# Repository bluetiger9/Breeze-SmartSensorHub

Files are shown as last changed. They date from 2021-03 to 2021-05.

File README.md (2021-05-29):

# Breeze: Smart Environmental Sensor Hub



Battery & Solar powered Sensor Hub with ML capabilities and supports a wide variety of Sensors and Communication Modules.

**Hackster.io**:
https://www.hackster.io/bluetiger9/breeze-smart-environmental-sensor-hub-fa496e

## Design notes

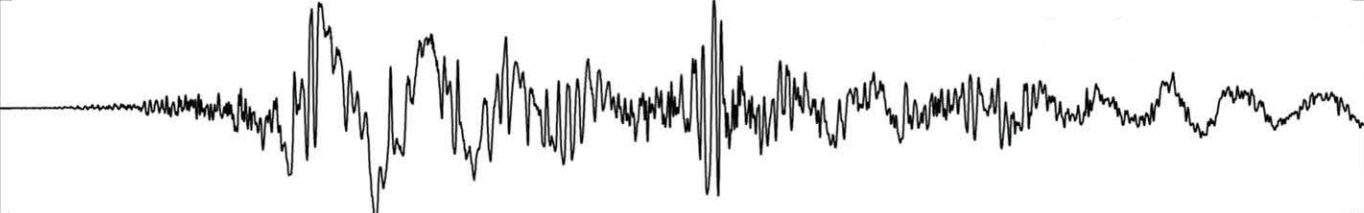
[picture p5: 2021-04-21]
Models/earthquake_data/s5-01-Y-scale-150cms2-70sec.png

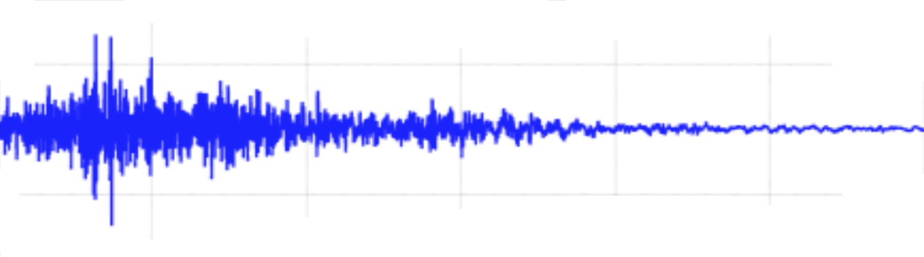
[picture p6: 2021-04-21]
Models/earthquake_data/s1-01-Z-scale-1G-60sec.png

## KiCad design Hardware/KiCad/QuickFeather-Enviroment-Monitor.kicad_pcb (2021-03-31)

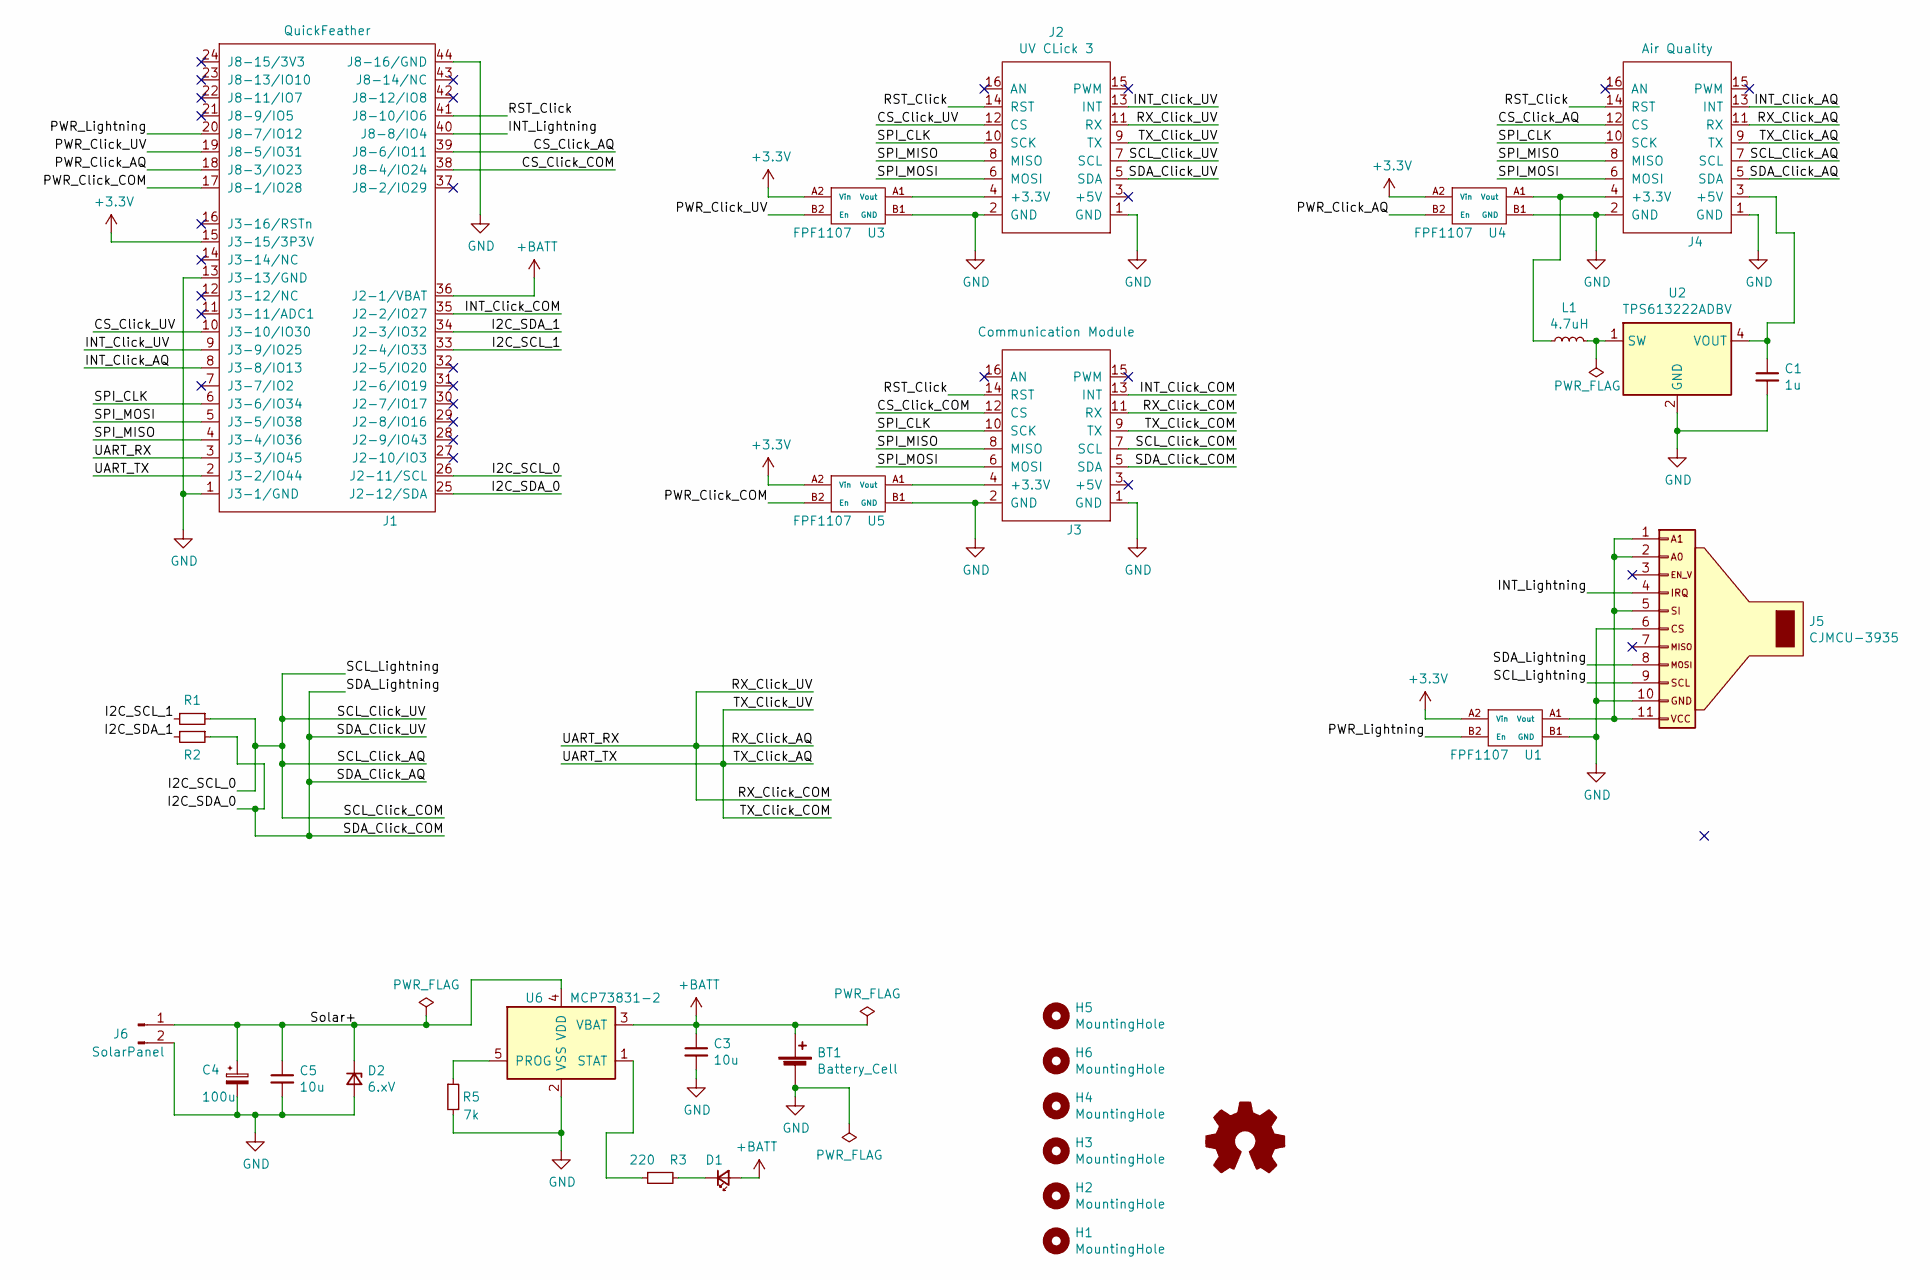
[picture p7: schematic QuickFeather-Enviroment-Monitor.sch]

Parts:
BT1: Battery_Cell; BatteryHolder_Keystone_1042_1x18650
C1: 1u; C_0805_2012Metric
C3, C5: 10u; C_0805_2012Metric
C4: 100u; CP_Radial_D6.3mm_P2.50mm
D1: LED_Small; LED_0805_2012Metric
D2: 6.xV; D_SMA
H1, H2, H3, H4, H5, H6: MountingHole
J1: QuickFeather; quickfeather
J2: UV CLick 3; MikroBUS-Small
J3: Communication Module; MikroBUS-Medium
J4: Air Quality; MikroBUS-Small
J5: CJMCU-3935
J6: SolarPanel; PinHeader_1x02_P2.54mm_Vertical
L1: 4.7uH; L_0805_2012Metric
R1, R2: nc; R_0402_1005Metric_Pad0.72x0.64mm_HandSolder
R3: 220; R_0805_2012Metric
R5: 7k; R_0805_2012Metric
U1, U3, U4, U5: FPF1107; BGA4C40P2X2_84X84X60N
U2: TPS613222ADBV; SOT-23-5
U6: MCP73831-2; SOT-23-5

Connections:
+3V3: J1.15 (J3-15/3P3V), U1.A2 (Vin), U3.A2 (Vin), U4.A2 (Vin), U5.A2 (Vin)
+BATT: BT1.1 (+), C3.1, D1.2 (A), J1.36 (J2-1/VBAT), U6.3 (VBAT)
/CS_Click_AQ: J1.39 (J8-6/IO11), J4.12 (CS)
/CS_Click_COM: J1.38 (J8-4/IO24), J3.12 (CS)
/CS_Click_UV: J1.10 (J3-10/IO30), J2.12 (CS)
/I2C_SCL_0: J1.26 (J2-11/SCL), J2.7 (SCL), J3.7 (SCL), J4.7 (SCL), J5.9, R1.1
/I2C_SCL_1: J1.33 (J2-4/IO33), R1.2
/I2C_SDA_0: J1.25 (J2-12/SDA), J2.5 (SDA), J3.5 (SDA), J4.5 (SDA), J5.8, R2.1
/I2C_SDA_1: J1.34 (J2-3/IO32), R2.2
/INT_Click_AQ: J1.8 (J3-8/IO13), J4.13 (INT)
/INT_Click_COM: J1.35 (J2-2/IO27), J3.13 (INT)
/INT_Click_UV: J1.9 (J3-9/IO25), J2.13 (INT)
/INT_Lightning: J1.40 (J8-8/IO4), J5.4
/PWR_Click_AQ: J1.18 (J8-3/IO23), U4.B2 (En)
/PWR_Click_COM: J1.17 (J8-1/IO28), U5.B2 (En)
/PWR_Click_UV: J1.19 (J8-5/IO31), U3.B2 (En)
/PWR_Lightning: J1.20 (J8-7/IO12), U1.B2 (En)
/RST_Click: J1.41 (J8-10/IO6), J2.14 (RST), J3.14 (RST), J4.14 (RST)
/RX_Click_AQ: J1.3 (J3-3/IO45), J2.11 (RX), J3.11 (RX), J4.11 (RX)
/SPI_CLK: J1.6 (J3-6/IO34), J2.10 (SCK), J3.10 (SCK), J4.10 (SCK)
/SPI_MISO: J1.4 (J3-4/IO36), J2.8 (MISO), J3.8 (MISO), J4.8 (MISO)
/SPI_MOSI: J1.5 (J3-5/IO38), J2.6 (MOSI), J3.6 (MOSI), J4.6 (MOSI)
/Solar+: C4.1, C5.1, D2.1 (K), J6.1, U6.4 (VDD)
/TX_Click_AQ: J1.2 (J3-2/IO44), J2.9 (TX), J3.9 (TX), J4.9 (TX)
GND: BT1.2 (-), C1.2, C3.2, C4.2, C5.2, D2.2 (A), J1.1 (J3-1/GND), J1.13 (J3-13/GND), J1.44 (J8-16/GND), J2.1 (GND), J2.2 (GND), J3.1 (GND), J3.2 (GND), J4.1 (GND), J4.2 (GND), J5.6, J5.10, J6.2, R5.2, U1.B1 (GND), U2.2 (GND), U3.B1 (GND), U4.B1 (GND), U5.B1 (GND), U6.2 (VSS)
unnamed: C1.1, J4.3 (+5V), U2.4 (VOUT)
unnamed: D1.1 (K), R3.2
unnamed: J2.4 (+3.3V), U3.A1 (Vout)
unnamed: J3.4 (+3.3V), U5.A1 (Vout)
unnamed: J4.4 (+3.3V), L1.1, U4.A1 (Vout)
unnamed: J5.1, J5.2, J5.5, J5.11, U1.A1 (Vout)
unnamed: L1.2, U2.1 (SW)
unnamed: R3.1, U6.1 (STAT)
unnamed: R5.1, U6.5 (PROG)

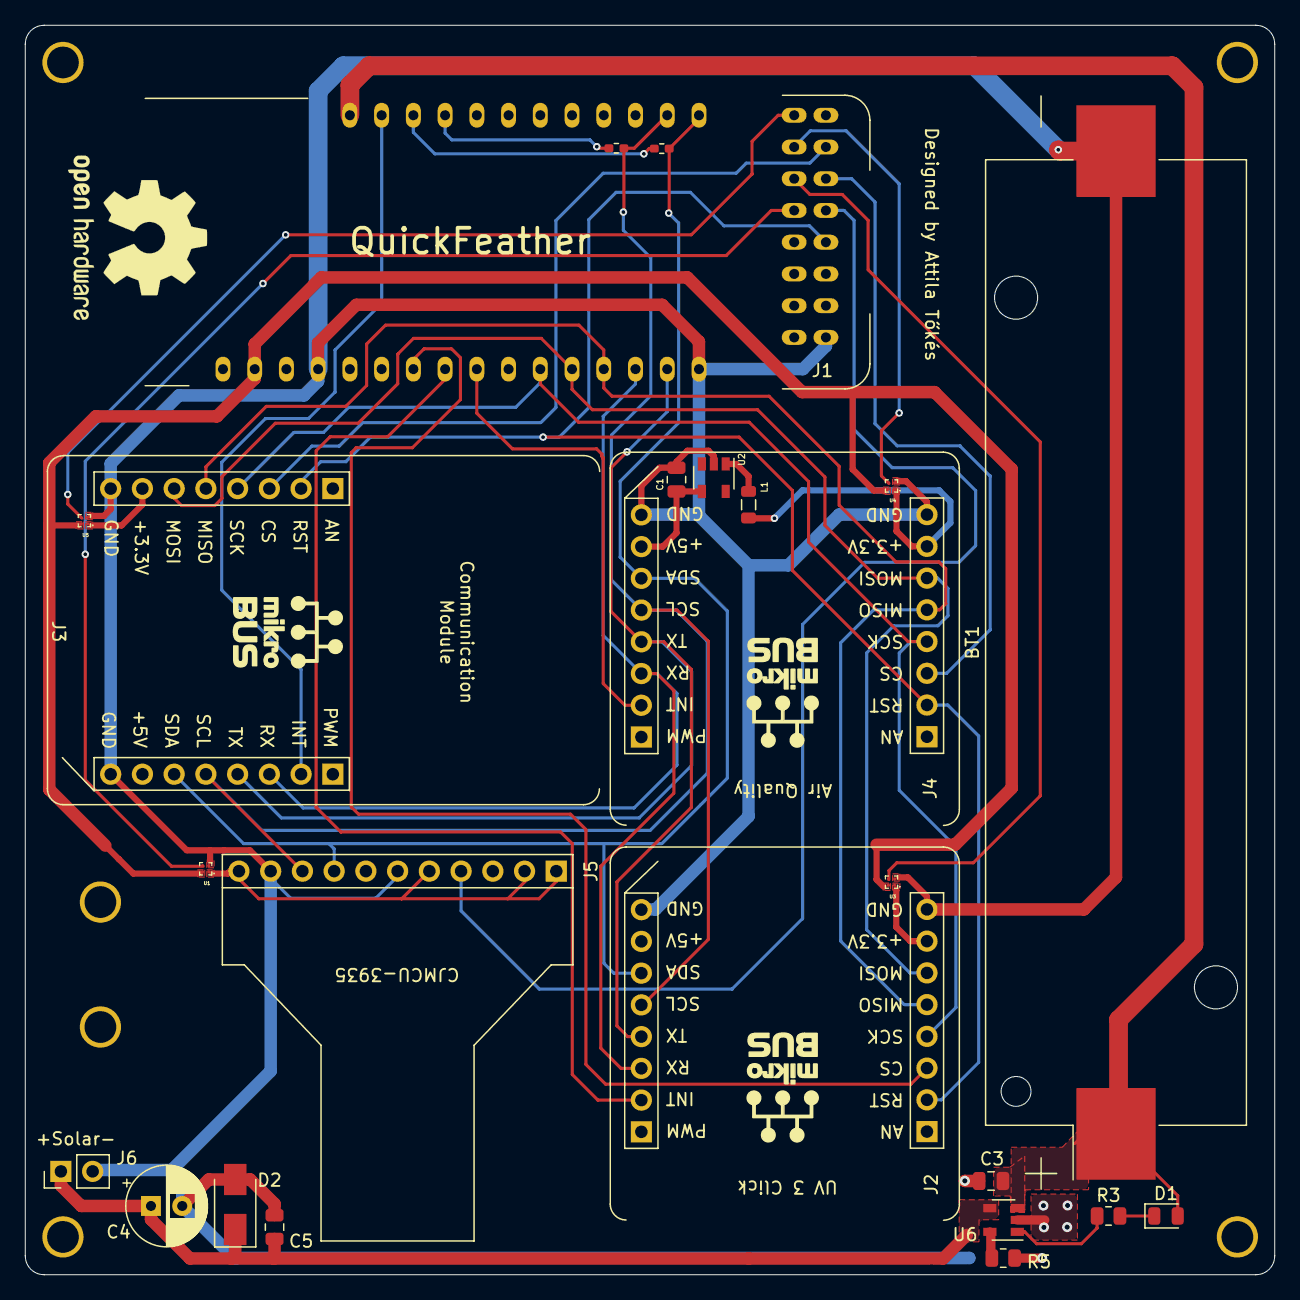
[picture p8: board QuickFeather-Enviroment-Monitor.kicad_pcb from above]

Board: 2 copper layers, 100.0 x 100.0 mm, 30 parts (0 on the bottom side), 34 nets.

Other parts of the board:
H5#2: MountingHole; MPAD

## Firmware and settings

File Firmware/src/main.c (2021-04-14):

/*==========================================================
 * Copyright 2020 QuickLogic Corporation
 *
 * Licensed under the Apache License, Version 2.0 (the "License");
 * you may not use this file except in compliance with the License.
 * You may obtain a copy of the License at
 *
 *    http://www.apache.org/licenses/LICENSE-2.0
 *
 * Unless required by applicable law or agreed to in writing, software
 * distributed under the License is distributed on an "AS IS" BASIS,
 * WITHOUT WARRANTIES OR CONDITIONS OF ANY KIND, either express or implied.
 * See the License for the specific language governing permissions and
 * limitations under the License.
 *==========================================================*/

/*==========================================================
 *
 *    File   : main.c
 *    Purpose: main for QuickFeather helloworldsw and LED/UserButton test
 *                                                          
 *=========================================================*/

#include "Fw_global_config.h"   // This defines application specific charactersitics

#include <stdio.h>
#include "FreeRTOS.h"
#include "task.h"
#include "semphr.h"
#include "timers.h"
#include "RtosTask.h"

/*    Include the generic headers required for QORC */
#include "eoss3_hal_gpio.h"
#include "eoss3_hal_rtc.h"
#if (FEATURE_USBSERIAL == 1)
#include "eoss3_hal_fpga_usbserial.h"
#endif
#if (FEATURE_FPGA_GPIO == 1)
//#include "eoss3_hal_fpga_gpio.h"
#include "hal_fpga_gpioctrl.h"
#include "fpga_gpio_top_bit.h"
#endif
#include "eoss3_hal_i2c.h"
#include "eoss3_hal_timer.h"
#include "ql_time.h"
#include "s3x_clock_hal.h"
#include "s3x_clock.h"
#include "s3x_pi.h"
#include "dbg_uart.h"
#include "sensor_ssss.h"
#include "ssi_comms.h"
#include "cli.h"
#include "fpga_loader.h"    // API for loading FPGA
#include "gateware.h"           // FPGA bitstream to load into FPGA
#include "kb.h"
#include "sensor_audio_config.h"
#include "sensor_audio_process.h"
#include "power.h"

extern const struct cli_cmd_entry my_main_menu[];

const char *SOFTWARE_VERSION_STR;

/*
 * Global variable definition
 */

static const fw_global_config_t fw_global_config_vars =
{
    .ssi_sensor_select_audio = SSI_SENSOR_SELECT_AUDIO,
	.sensor_audio_livestream_enabled = SENSOR_AUDIO_LIVESTREAM_ENABLED,
	.sensor_audio_recog_enabled = SENSOR_AUDIO_RECOG_ENABLED,

	.ssi_sensor_select_ssss = SSI_SENSOR_SELECT_SSSS,
    .sensor_ssss_livestream_enabled = SENSOR_SSSS_LIVESTREAM_ENABLED,
    .sensor_ssss_recog_enabled = SENSOR_SSSS_RECOG_ENABLED
};

#if 1
static I2C_Config i2c0config =
{
  .eI2CFreq = I2C_100KHZ,    // 400kHz
  .eI2CInt = I2C_DISABLE,    // enabled interrupt
  .ucI2Cn = 0
};
#endif
extern void qf_hardwareSetup();
static void nvic_init(void);

int main(void)
{

    SOFTWARE_VERSION_STR = "qorc-sdk/qf_apps/qf_ssi_app";
    
    qf_hardwareSetup();
    nvic_init();
#if (FEATURE_USBSERIAL == 1)
    S3x_Clk_Disable(S3X_FB_21_CLK);
    S3x_Clk_Disable(S3X_FB_16_CLK);
    S3x_Clk_Enable(S3X_A1_CLK);
    S3x_Clk_Enable(S3X_CFG_DMA_A1_CLK);
    load_fpga(axFPGABitStream_length,axFPGABitStream);
    // Use 0x6141 as USB serial product ID (USB PID)
	//HAL_usbserial_init2(false, true, 0x6141);        // Start USB serial not using interrupts
    //for (int i = 0; i != 4000000; i++) ;   // Give it time to enumerate
#endif
#if (FEATURE_FPGA_GPIO == 1)
    S3x_Clk_Disable(S3X_FB_21_CLK);
    S3x_Clk_Disable(S3X_FB_16_CLK);
    S3x_Clk_Enable(S3X_A1_CLK);
    S3x_Clk_Enable(S3X_CFG_DMA_A1_CLK);
    load_fpga(sizeof(axFPGABitStream_GPIO),axFPGABitStream_GPIO);
    S3x_Clk_Set_Rate(S3X_FB_21_CLK, 12000*1000);
    S3x_Clk_Set_Rate(S3X_FB_16_CLK, 12000*1000);
    S3x_Clk_Enable(S3X_FB_21_CLK);
    S3x_Clk_Enable(S3X_FB_16_CLK);
#endif
    dbg_str("\n\n");
    dbg_str( "##########################\n");
    dbg_str( "Quicklogic QuickFeather SensiML AI Data Collection/Recognition App\n");
    dbg_str( "SW Version: ");
    dbg_str( SOFTWARE_VERSION_STR );
    dbg_str( "\n" );
    dbg_str( __DATE__ " " __TIME__ "\n" );
    dbg_str( "##########################\n\n");
	
	dbg_str( "\n\nHello world!!\n\n");	// <<<<<<<<<<<<<<<<<<<<<  Change me!
    HAL_Delay_Init();
#if (PDM_PAD_28_29 == 1)
    IO_MUX->PDM_DATA_SELE = 0x02;   // 1 for pad10, 2 for pad28
#endif
#if (PDM_PAD_8_10 == 1)
    IO_MUX->PDM_DATA_SELE = 0x01;   // 1 for pad10, 2 for pad28
#endif
#if (VOICE_AP_BYPASS_MODE == 1)
    /* Select for PAD 38 */
    IO_MUX->PDM_CLKIN_SEL = 0x01;
#endif

    // power cycle modules:
    power(AQ, false);
    power(UV, false);
    power(LH, false);
    power(COM, false);

    delay(3000);

    power(AQ, true);
    power(UV, true);
    power(LH, true);
    power(COM, true);

    cs(AQ, true);
    cs(UV, true);
    cs(LH, true);
    cs(COM, true);

    HAL_I2C_Init(i2c0config);

    kb_model_init(); /* initialize the knowledgepack */
#if (SSI_SENSOR_SELECT_SSSS == 1)
    sensor_ssss_block_processor();
#endif

#if (SSI_SENSOR_SELECT_AUDIO == 1)
    audio_block_processor();

#if (SENSOR_AUDIO_RECOG_ENABLED == 1)
    sensor_audio_add();
    sensor_audio_startstop(1);
#endif

#endif /* SSI_SENSOR_SELECT_AUDIO */

#if ( ((SSI_SENSOR_SELECT_SSSS == 1) && (SENSOR_SSSS_LIVESTREAM_ENABLED == 1)) || \
      ((SSI_SENSOR_SELECT_AUDIO == 1) && (SENSOR_AUDIO_LIVESTREAM_ENABLED == 1)) )
    StartSimpleStreamingInterfaceTask();
#endif

    /* Start the tasks and timer running. */
    vTaskStartScheduler();
    dbg_str("\n");
      
    while(1);
}

static void nvic_init(void)
 {
    // To initialize system, this interrupt should be triggered at main.
    // So, we will set its priority just before calling vTaskStartScheduler(), not the time of enabling each irq.
    NVIC_SetPriority(Ffe0_IRQn, configLIBRARY_MAX_SYSCALL_INTERRUPT_PRIORITY);
    NVIC_SetPriority(SpiMs_IRQn, configLIBRARY_MAX_SYSCALL_INTERRUPT_PRIORITY);
    NVIC_SetPriority(CfgDma_IRQn, configLIBRARY_MAX_SYSCALL_INTERRUPT_PRIORITY);
    NVIC_SetPriority(Uart_IRQn, configLIBRARY_MAX_SYSCALL_INTERRUPT_PRIORITY);
    NVIC_SetPriority(FbMsg_IRQn, configLIBRARY_MAX_SYSCALL_INTERRUPT_PRIORITY);
 }    

//needed for startup_EOSS3b.s asm file
void SystemInit(void)
{

}

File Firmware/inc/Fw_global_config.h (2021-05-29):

/*==========================================================
 * Copyright 2020 QuickLogic Corporation
 *
 * Licensed under the Apache License, Version 2.0 (the "License");
 * you may not use this file except in compliance with the License.
 * You may obtain a copy of the License at
 *
 *    http://www.apache.org/licenses/LICENSE-2.0
 *
 * Unless required by applicable law or agreed to in writing, software
 * distributed under the License is distributed on an "AS IS" BASIS,
 * WITHOUT WARRANTIES OR CONDITIONS OF ANY KIND, either express or implied.
 * See the License for the specific language governing permissions and
 * limitations under the License.
 *==========================================================*/

/*==========================================================
 *
 *    File   : Fw_global_config.h
 *    Purpose:
 *
 *=========================================================*/

#ifndef FW_GLOBAL_CONFIG_H_INCLUDED     /* Avoid multiple inclusion             */
#define FW_GLOBAL_CONFIG_H_INCLUDED

#include <stdint.h>
#include "sec_debug.h"
//#include "eoss3_hal_uart.h"

#define ENABLE_VOICE_SOLUTION   1
#define PDM2DEC_FACT  48

#define FEATURE_CLI_DEBUG_INTERFACE  1
#define FEATURE_CLI_FILESYSTEM       0

/* Select the filesystem API to use */
#define USE_FREERTOS_FAT         1  ///< Set this to 1 to use FreeRTOS FAT filesystem (Merced default)
#define USE_FATFS                0  ///< Set this to 1 to use FATFs filesystem

/* use this flag to check the data block header */
/* can be used only iff the QL_XPORT_INCLUDE_HEADER is defined for Device */
#define TST_HEADER_VERIFY (1)

/* future may have other modes? */

#define uartHandlerUpdate(id,x)

#define FEATURE_FPGA_UART   0       // FPGA UART not present
#define FEATURE_USBSERIAL   0       // USBSERIAL port is present
#define FEATURE_FPGA_GPIO   1       // FPGA_GPIO

//#define QLUART_ENABLE 1

// Options for debug output -- use to set DEBUG_UART below
// #define UART_ID_DISABLED     0   // /dev/null */
#define UART_ID_HW           1   // the hard UART on the S3
// #define UART_ID_SEMIHOST     2   // Write debug data to semihost
// #define UART_ID_FPGA         3   // second uart if part of FPGA
// #define UART_ID_BUFFER       4   // Write data to buffer
// #define UART_ID_SEMBUF       5   // Write data to semihost and buffer
// #define UART_ID_USBSERIAL    6   // Write data to USB serial port
//#define DEBUG_UART  UART_ID_BUFFER  // Write data to USB serial port
//#define DEBUG_UART  UART_ID_USBSERIAL
#define DEBUG_UART  UART_ID_SEMIHOST
//#define DEBUG_UART  UART_ID_DISABLED

//#define USE_SEMIHOSTING     0       // 1 => use semihosting, 0 => use UART_ID_HW
#define USE_SEMIHOSTING     1      // 1 => use semihosting, 0 => use UART_ID_HW

#define SIZEOF_DBGBUFFER    2048    // Number of characters in circular debug buffer

/* Select the UART ID for Simple Streaming Interface */
#define UART_ID_SSI             (UART_ID_HW)
//#define UART_ID_SSI  (UART_ID_USBSERIAL)

#define UART_ID_PMS7003         (UART_ID_HW)
#define UART_ID_WIFI_ESP_CLICK         (UART_ID_HW)

// Toggle GPIO whenever a datablock buffer is dispatched to the UART
// Datablocks are dispatched every (SENSOR_SSSS_LATENCY) ms. Default is 20ms or 50Hz
//#define SENSOR_SSSS_RATE_DEBUG_GPIO      (1)    // Set to 1 to toggle configured GPIO
#define SENSOR_SSSS_RATE_DEBUG_GPIO      (0)    // Set to 1 to toggle configured GPIO

/* Setting this MACRO to 1 enables sending a known sawtooth pattern as live-stream
 * sensor data, this setting is intended for verifying communication interface
 */
#define SENSOR_COMMS_KNOWN_PATTERN (0) // 1 => Send a known sawtooth pattern for live-streaming

/* Settings for selecting either Audio or an I2C sensor, Enable only one of these mode */
#define SSI_SENSOR_SELECT_AUDIO    (0) // 1 => Select Audio data for live-streaming or recognition modes
#define SSI_SENSOR_SELECT_SSSS     (1) // 1 => Select SSSS sensor data for live-streaming of recognition modes

#if (SSI_SENSOR_SELECT_AUDIO == 1) && (SSI_SENSOR_SELECT_SSSS == 1)
#error "Enable only one of the sensors SSI_SENSOR_SELECT_AUDIO or SSI_SENSOR_SELECT_SSSS"
#endif

#define DBG_flags_default 0 //  (DBG_FLAG_ble_cmd + DBG_FLAG_sensor_rate+DBG_FLAG_datasave_debug)
#define DBG_FLAGS_ENABLE 1
#if !DBG_FLAGS_ENABLE
#define DBG_flags 0
#else
extern uint32_t DBG_flags;
#endif

extern const char *SOFTWARE_VERSION_STR;

extern int FPGA_FFE_LOADED;

#define ENABLE_PRINTF 1

/** Enable Host mode for Voice application, This standalone S3 mode */

#define HOST_VOICE  0


/** Define COMPANION_SENSOR macro to configure system in CO-PROCESSOR mode for double tap application */
//#define COMPANION_SENSOR

/** Define HOST_SENSOR macro to configure system in HOST mode  */
#define HOST_SENSOR 1

#if !defined(ENABLE_PRINTF)
#include <stdio.h> /* we require printf() to be defined first */
#define printf(x, ...) 	/* Uart is disabled in CO-PROCESSOR_VOICE for power numbers */
#endif
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

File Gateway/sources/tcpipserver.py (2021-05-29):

import json
import struct
import math
import time
import random
import socket
import threading
import copy
from sources.base import BaseReader, BaseResultReaderMixin, BaseStreamReaderMixin

WIFI_PORT = ":80"

class TCPServer():
    def __init__(self):
        print("TCP Server create")
        self.started = False
        self.config_line = None
        pass
        
    def start(self, address, port):
        if self.started:
            print("TCP Server already started")
            return
            
        self.address = address
        self.port = port
        
        self.conn_accept_thread = threading.Thread(target = self.conn_accept_thread_func, args=[])
        self.conn_accept_thread.start()
        while self.config_line != None:
            continue
    
    def conn_thread_func(self, conn, addr):
        print("Conn handler {}".format(addr))
        confile = conn.makefile()
        line = ""
        while "\n" not in line:
            bytes = confile.read(1)
            line = line + bytes
            print("bytes {}".format(bytes, type(bytes)))
        #line = confile.readline()
        print("line {}".format(line))
        self.conn = conn
        self.confile = confile
        self.config_line = line
        
    def conn_accept_thread_func(self):    
        print("TCP Server start")
        self.started = True
        try:
            with socket.socket(socket.AF_INET, socket.SOCK_STREAM) as s:
                print("bind {}:{}".format(self.address, self.port))
                s.setsockopt(socket.SOL_SOCKET, socket.SO_REUSEADDR, 1)
                s.bind((self.address, self.port))
                s.listen()
                while True:
                    conn, addr = s.accept()
                    print('Connected by', addr)
                    conn_thread = threading.Thread(target = self.conn_thread_func, args=[conn, addr])
                    conn_thread.start()
                    #self.conn = conn
                    #self.confile = conn.makefile()

        except Exception as e:
            print(e)
            self.disconnect()
            raise e
          
            
tcpServer = TCPServer()

    
class TCPIPServerReader(BaseReader):
    def __init__(self, config, device_id, **kwargs):

        self.device_id = device_id

        if kwargs.get("connect", True) is True:
            self._address = "0.0.0.0"
            self._port = int(device_id)
        
        print("TCP server reader create")
        tcpServer.start(self.address, self.port)
            
        super(TCPIPServerReader, self).__init__(config, device_id, **kwargs)
        

    @property
    def address(self):
        return self._address

    @property
    def port(self):
        return self._port


class TCPIPServerStreamReader(TCPIPServerReader, BaseStreamReaderMixin):
    def read_device_config(self):
        print("read device config")
        while tcpServer.config_line is None:
            continue
        line = tcpServer.config_line
        print(line)
        jsonline = json.loads(line)
        print("jsonline: {}".format(jsonline))
        return self._validate_config(jsonline)

    def _read_source(self):
        print("read sorce")
        try:            
            self.streaming = True            
            while True:
                #line = tcpServer.confile.readline()
                data = tcpServer.conn.recv(self.source_buffer_size)
                print("d:'{}'".format(data))
                if b"CIPSEND" in data:
                   print("garbage filtered out")
                   continue

                self.buffer.update_buffer(data)
                time.sleep(0.0001)

        except Exception as e:
            print(e)
            self.disconnect()
            raise e

    def set_app_config(self, config):
        config["DATA_SOURCE"] = "TCPIPSERVER"
        config["CONFIG_COLUMNS"] = self.config_columns
        config["CONFIG_SAMPLE_RATE"] = self.sample_rate
        config["SOURCE_SAMPLES_PER_PACKET"] = self.source_samples_per_packet
        config["DEVICE_ID"] = self.device_id


class TCPIPServerResultReader(TCPIPServerReader, BaseResultReaderMixin):
    def set_app_config(self, config):
        config["DATA_SOURCE"] = "TCPIPSERVER"
        config["DEVICE_ID"] = self.device_id

    def _read_source(self):
        self.streaming = True

        with s.get(url, headers=None, stream=True) as resp:
            content = ""

            for cont in resp.iter_content():

                if not self.streaming:
                    return

                try:
                    data = cont.decode("ascii")
                except Exception as e:
                    print(e)
                    continue

                if data == "}":
                    content += data
                    self.rbuffer.update_buffer([content])
                    content = ""
                elif data == "{":
                    content = data
                else:
                    content += data


if __name__ == "__main__":
    device_id = "192.168.86.27:80"
    config = {
        "CONFIG_SAMPLES_PER_PACKET": 10,
        "CONFIG_SAMPLE_RATE": 100,
        "CONFIG_COLUMNS": ["X", "Y", "Z"],
    }

    import threading
    import time

    """
    reader =  TCPResultReader(config, device_id)
    """

    reader = TCPIPReader(config, device_id)

    print(reader.read_config())
    # print(reader._read_sensor_data())

    for data in reader.read_data():
        print(data)

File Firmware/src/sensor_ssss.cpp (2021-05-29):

/** @file sensor_ssss_process.c */

/*==========================================================
 * Copyright 2020 QuickLogic Corporation
 *
 * Licensed under the Apache License, Version 2.0 (the "License");
 * you may not use this file except in compliance with the License.
 * You may obtain a copy of the License at
 *
 *    http://www.apache.org/licenses/LICENSE-2.0
 *
 * Unless required by applicable law or agreed to in writing, software
 * distributed under the License is distributed on an "AS IS" BASIS,
 * WITHOUT WARRANTIES OR CONDITIONS OF ANY KIND, either express or implied.
 * See the License for the specific language governing permissions and
 * limitations under the License.
 *==========================================================*/

#include <stdbool.h>
#include <stdio.h>
#include <string.h>
#include "FreeRTOS.h"
#include "task.h"
#include "semphr.h"
#include "timers.h"

#include "datablk_mgr.h"
#include "process_ids.h"
#include "datablk_processor.h"
#include "sensor_ssss.h"
#include "micro_tick64.h"
#include "dbg_uart.h"
#include "ssi_comms.h"
#include "eoss3_hal_i2c.h"

#include "mc3635_wire.h"
#include "sml_recognition_run.h"

#include "Adafruit_VEML6070.h"
#include "SparkFun_AS3935.h"
#include "pms7003.h"

#include "kb.h"
#include "delay.h"

// When enabled, GPIO (configured in pincfg_table.c) is toggled whenever a
// datablock is dispacthed for writing to the UART. Datablocks are dispatched
// every (SENSOR_SSSS_LATENCY) ms
#if (SENSOR_SSSS_RATE_DEBUG_GPIO == 1)
#include "eoss3_hal_gpio.h"
uint8_t sensor_rate_debug_gpio_val = 1;
#endif

/* BEGIN user include files
 * Add header files needed for accessing the sensor APIs
 */

/* User settable MACROs */

/* This section defines MACROs that may be user modified */

// Accelerometer
MC3635  qorc_ssi_accel;
int16_t accX0, accY0, accZ0;

// UV
Adafruit_VEML6070 uv;

// Lightning
#define AS3935_ADDR 0x03
#define INDOOR 0x12
#define OUTDOOR 0xE
#define LIGHTNING_INT 0x08
#define DISTURBER_INT 0x04
#define NOISE_INT 0x01

SparkFun_AS3935 lightning(AS3935_ADDR);

int intVal = 0;
int noise = 2; // Value between 1-7
int disturber = 2; // Value between 1-10

const int16_t LIGHTNING_NOISE = -1;
const int16_t LIGHTNING_DISTURBER = -2;

DATA lastPmsData;

int16_t lastEarthquakeDetection = -3;

/* User modifiable sensor descriptor in JSON format */
#if (SSI_SENSOR_SELECT_SSSS == 1)

/* BEGIN JSON descriptor for the sensor configuration */

const char json_string_sensor_config[] = \
"{"\
   "\"sample_rate\":100,"\
   "\"samples_per_packet\":16,"\
   "\"column_location\":{"\
	"  \"AccelerometerX\":0,"\
	"  \"AccelerometerY\":1,"\
	"  \"AccelerometerZ\":2,"\
	"  \"UV\":3,"\
	"  \"Lightning\":4,"\
	"  \"PM1\":5,"\
	"  \"PM2.5\":6,"\
	"  \"PM10\":7,"\
	"  \"EarthquakeDetect\":8"\
   "}"\
"}\r\n";
/* END JSON descriptor for the sensor data */
#endif /* SSI_SENSOR_SELECT_SSSS */

/* User modifiable function. Update the below function
 * to initialize and setup I2C sensors */
void sensor_ssss_configure(void)
{
  /** @todo Replace contents of this function */
  sensor_ssss_config.rate_hz = SENSOR_SSSS_SAMPLE_RATE_HZ;
  sensor_ssss_config.n_channels = SENSOR_SSSS_CHANNELS_PER_SAMPLE;
  sensor_ssss_config.bit_depth = SENSOR_SSSS_BIT_DEPTH;
  sensor_ssss_config.sensor_id = SENSOR_SSSS_ID;
  static int sensor_ssss_configured = false;

  /*--- BEGIN User modifiable section ---*/

  // Accelerometer begin
  qorc_ssi_accel.begin();
  qorc_ssi_accel.set_sample_rate(sensor_ssss_config.rate_hz);
  qorc_ssi_accel.set_sample_resolution(sensor_ssss_config.bit_depth);
  qorc_ssi_accel.set_mode(MC3635_MODE_CWAKE);

  delay(500);

  // calibrate based on the initial position
  int32_t xx0 = 0, yy0 = 0, zz0 = 0;
  for (int i = 0; i < 16; ++i) {
      xyz_t accel_data = qorc_ssi_accel.read();
      xx0 += accel_data.x;
      yy0 += accel_data.y;
      zz0 += accel_data.z;
  }
  accX0 = xx0 / 16;
  accY0 = yy0 / 16;
  accZ0 = zz0 / 16;

  // UV begin
  uv.begin(VEML6070_1_T);

  // Lightning begin
  if (lightning.begin()) {
	  dbg_str("Lightning sensor initialized.\n");

  } else {
	  dbg_str("Failed to initialize lightning sensor!\n");
  }

  // Air Quality
  pms_init(UART_ID_PMS7003);

  /*--- END of User modifiable section ---*/

  if (sensor_ssss_configured == false)
  {
    sensor_ssss_configured = true;
  }
  sensor_ssss_startstop(1);
}

/* User modifiable function. Update the below function
 * to read sensor data sample from sensors and fill-in
 * the data block with these sensor data values */
int  sensor_ssss_acquisition_buffer_ready()
{
    int8_t *p_dest = (int8_t *) &psensor_ssss_data_block_prev->p_data;
    int dataElementSize = psensor_ssss_data_block_prev->dbHeader.dataElementSize;
    int ret;
    int batch_size;

    p_dest += sizeof(int8_t)*sensor_ssss_samples_collected*dataElementSize;

    /* Read 1 sample per channel, Fill the sample data to p_dest buffer */

    /*--- BEGIN User modifiable section ---*/

    // Accelerometer
    xyz_t accel_data = qorc_ssi_accel.read();  /* Read accelerometer data from MC3635 */

    /* Fill this accelerometer data into the current data block */
    int16_t *p_accel_data = (int16_t *)p_dest;
    int16_t *p_accel_data_recog = (int16_t *)p_dest;

    *p_accel_data++ = accel_data.x - accX0;
    *p_accel_data++ = accel_data.y - accY0;
    *p_accel_data++ = accel_data.z - accZ0;

    p_dest += 6; // advance datablock pointer to retrieve and store next sensor data

    // UV
    int16_t uv_value = uv.readUV(false);

    int16_t *p_uv_data = (int16_t *)p_dest;
    *p_uv_data++ = uv_value;

    p_dest += 2;

    // Lightning
    //if(digitalRead(lightningInt) == HIGH){
    int16_t lightning_value = 0;
	if (true) {
		// Hardware has alerted us to an event, now we read the interrupt register
		// to see exactly what it is.
		intVal = lightning.readInterruptReg();
		if (intVal == NOISE_INT) {
			//dbg_str("Noise.");
			lightning_value = LIGHTNING_NOISE;
			// Too much noise? Uncomment the code below, a higher number means better
			// noise rejection.
			//lightning.setNoiseLevel(setNoiseLevel);
		} else if (intVal == DISTURBER_INT) {
//			dbg_str("Disturber.");
			lightning_value = LIGHTNING_DISTURBER;
			// Too many disturbers? Uncomment the code below, a higher number means better
			// disturber rejection.
			//lightning.watchdogThreshold(threshVal);
		} else if (intVal == LIGHTNING_INT) {
			dbg_str("Lightning Strike Detected!");
			// Lightning! Now how far away is it? Distance estimation takes into
			// account any previously seen events in the last 15 seconds.
			uint16_t distance = lightning.distanceToStorm();
			dbg_str("Approximately: ");
			dbg_int(distance);
			lightning_value = distance;
			dbg_str("km away!\n");
		}

	    int16_t *p_lightning_data = (int16_t *)p_dest;
	    *p_lightning_data = lightning_value;
	    p_dest += 2;
	}

	// Air Quality
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

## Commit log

2021-03-31 KiCad project
    [QuickFeather-Enviroment-Monitor-B_Cu.gbr, QuickFeather-Enviroment-Monitor-B_Mask.gbr, QuickFeather-Enviroment-Monitor-B_SilkS.gbr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]
2021-04-04 UV 3 Click / VEML6070 driver
2021-04-04 CJMCU-3935 / AS3935 Lightning sensor driver
2021-04-11 GPIO driver (normal + FPGA) for Power and Chip Select pins
2021-04-13 PMS7003 driver
2021-04-14 Wifi ESP Click / Communication Module driver + protocol
2021-04-15 Gateway Application (initial commit)
    Source: https://github.com/sensiml/simple-streaming-gateway.git
    [filename.csv]
2021-04-18 Firmware: calibrate accelerometer
